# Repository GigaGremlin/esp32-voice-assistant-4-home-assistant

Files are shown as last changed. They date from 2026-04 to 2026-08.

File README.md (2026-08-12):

# 🎙️ ESP32 Voice-Assistant für Home Assistant

<div align="center">
  VA-Moon
</div>

---

## Über dieses Projekt

**(ESP32-S3 WROOM-1-N16-R8) Home Assistant Voice Assistant Pro Version**

Meinen Ersatz für den M5AtomEcho gibt es jetzt auch in der Pro Version als Voice Assistant für Home Assistant.

Die Pro Version meines “Voice Assistant“ unterscheidet sich von der Standardausführung durch ein zusätzlich integriertes Radarmodul, einen kleinen physikalischen Button auf der Rückseite und einen vorgeschalteten “CH224K USB-C Schnellladeregler“. Die nötige Pinbelegung für den Anschluss am “ESP32“ findet sich wie immer als Tabelle in meiner “YAML-Firmware-Datei“.

**Update: ab sofort funktioniert Music Assistant mit meiner letzten Firmware einwandfrei!!!**

Die Liste der Komponenten ist wie gewohnt sehr einfach und preiswert gehalten.

Ich verwende die üblichen Verdächtigen: einen Max98357A als Verstärker und ein INMP441 als Mikrofon. Die LED ist eine adressierbare WS2812 mit 5 Volt. Für die gestiegenen Anforderungen habe ich jetzt einen CH224K USB-C Schnellladeregler als Spannungsverteiler vorgeschaltet. Durch dessen Verwendung könnte man jetzt sogar mehrere LEDs anbinden (Einfach die LED-Anzahl in der YAML erhöhen) oder andere Sensor-Module einbinden.

Und was Preis und Leistung angeht, ist dieser Voice Assistant für Home Assistant, gemessen an vergleichbaren Assistenten, immer noch deutlich preiswerter und durch den integrierten Präsenzmelder ist er sogar überlegen, da Anbindung & Steuerung nicht über eine zusätzliche Bluetooth- oder ZigBee-Verbindung erfolgt.

* **Baukosten ohne den 3D Druck:** ca. 35€
* **Geschätzter Marktwert:** 80-120 Euro

---

**(ESP32-S3 WROOM-1-N16-R8) Home Assistant Voice Assistant Pro Version**

My replacement for the M5AtomEcho is now also available in a Pro Version as a Voice Assistant for Home Assistant.

The Pro Version of my "Voice Assistant" differs from the standard model by including an additional radar module, a small physical button on the back, and a preceding "CH224K USB-C Fast Charge Controller". As always, the necessary pinout for connecting to the "ESP32" can be found as a table in my "YAML firmware file."

**Update: Music Assistant is now working perfectly with my latest firmware!!!**

The component list is, as usual, kept very simple and inexpensive. I am using the usual suspects: a Max98357A as an amplifier and an INMP441 as a microphone. The LED is an addressable WS2812 operating at 5 volts. To meet the increased demands, I have now installed a CH224K USB-C Fast Charge Controller as a preceding voltage distributor. By using it, you could now even connect multiple LEDs (simply increase the LED count in the YAML) or integrate other sensor modules.

Regarding price and performance, this Voice Assistant for Home Assistant is still significantly less expensive compared to similar assistants, and due to the integrated presence detector, it is even superior, as connection and control do not require an additional Bluetooth or ZigBee link.

* **Construction costs without 3D print:** approx. €35
* **Estimated market value:** €80–120

---

> [!NOTE]
> **Anschlussbelegung:** Die notwendige Anschlussbelegung ist natürlich in die YAML-Datei integriert. / The necessary pin assignment is integrated into the YAML file.

<div align="center">
  Pinbelegung
</div></div>

---
<div align="center">
OldPinOut
</div></div>

---

<div align="center">
  InsideView
</div></div>

---
* **Achtung !!!** - Da ich für meine letzten S3 Module die preiswerten Versionen von Ali gekauft habe und es mir nicht gelungen ist darauf die gleiche Standardkonfiguration zum laufen zu bringen, wie bei meinen Marken Modulen,
verstehe ich jetzt auch die Probleme, die einige von Euch beim Nachbau hatten.
* Um diese Probleme direkt zu beseitigen, habe ich nun doch die GPIO's für den MAX98357 und das INMP441 getrennt und eine eigene Firmware, basierend auf der neuen Verkabelung erstellt.
* Mit dieser Änderung funktionieren dann auch die Klon-Module als Voice Assistant und Music Assistant Satelliten. 
* Und das lästige Störgeräusch beim Booten ist damit ebenfalls Geschichte.
* **Das Video zur Neuerung ist noch in Arbeit**
---
<div align="center">
NewPinOut
</div></div>

---

# YouTube: ESP32 S3 Voice Assistant Pro

<div align="center">
  <a href="https://youtu.be/G6M7URdppqs">
    Video Anleitung
  </a>
  <p>📺 <i>Klicke auf das Bild, um das Video auf YouTube zu starten</i></p>
</div>

---

## 🛠️ Downloads & Firmware

Wähle die passende Version für deine Hardware:

### 1. Firmware old PinOut Version (YAML Dateien)
* 📥 [**Standard Version**](firmware/standard/) – Ohne Radar-Modul.
* 📥 [**Radar Version**](firmware/radar/) – Optimiert für Anwesenheitserkennung.
* *******************************************************************************
### 2. Firmware new PinOut Version (YAML Dateien)
**(Achtung - Bitte nur noch die Neue Version verwenden !!!)**
* 📥 [**New PinOut Version - Universal Version**](firmware/new/) – Optimiert für alle S3 Module.
  
**Aber was, wenn ich kein Radar-Modul will ??!**

... kein Problem, dann diese Kabel einfach weglassen...
Meine neue Firmware-GUI Version kann jetzt beide Varianten aus der 
neuen Universal-Firmware für Deine Home Assistant Ansprüche erstellen. 

Wer kein LD2410 Radar Modul nutzt, kann einfach den Haken in der GUI weglassen. 
Die Standardeinstellung ist ausgeschaltet, aber alle anderen sollten den Haken setzen! 
Hier kann jetzt auch direkt an einigen anderen “Stellschrauben“ gedreht werden.

* *******************************************************************************
* 📁 [Alle Firmware-Versionen durchsuchen](firmware/)
* *******************************************************************************

### 3. Tools & Personalisierung
**Achtung !!!** - für die NEUE universal Firmware gibt 

es auch ein neues GuiTool, **New-ESPhome_GUI.exe**

* 🖥️ [**GGFW Personalizer Tool (EXE)**](gui-tool/)
* 🖥️ [**New-ESPhome_GUI (EXE)**](gui-tool/)
  
**Nutze dieses Tool, um WLAN-Daten und Namen direkt in der Firmware anzupassen.**
* *******************************************************************************

### 4. Gehäuse & 3D-Druck
* 📐 [3D-Druck Dateien (STL)](3D-Print/)

**Es gibt jetzt auch eine neue universal 2,5"-Speaker-Halterung die mit M4 Schrauben funktioniert.**
* *******************************************************************************

### 5. Home Assistant - Integration
* 🏠 [**Home Assistant Beispiel-Konfigurationen**](home-assistant-examples/)

**Hier findest du YAML-Ausschnitte für Dashboards und Automatisierungen.**

</div></div>

---

<div align="center">
<i>Zuletzt aktualisiert: August 2026</i>
</div>

</div></div>   
<div align="center">
   <a href="https://gigagremlin.de">
    
  </a>
</div>

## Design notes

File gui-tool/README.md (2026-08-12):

# GigGremlin Firmware Personalizer GUI

**Dieses kleine GUI soll dabei helfen die Firmware einfacher an die persönlichen Bedürfnisse im Netzwerk anzupassen.**
**So kann der Name und die IP schnell geändert werden. Das ist gerade bei mehreren Geräten hilfreich und spart Zeit.**
**Darüber hinaus kann ich nur jedem dazu raten eine feste IP für seine VA’s zu verwenden.**

This small GUI is designed to help you easily adapt the firmware to your individual network needs. 
For example, you can quickly change the name and IP address. This is especially helpful with multiple devices 
and saves time. Furthermore, I strongly recommend using a static IP address for your virtual assistants.

--- 
GigGremlinFirmwarePersonalizerGUI

---
GigGremlinFirmwarePersonalizerGUI-2

---
# **Achtung** - neues Firmware GUI für das **NEUE** Pin Layout !!!

---
GG-VA-FWTool

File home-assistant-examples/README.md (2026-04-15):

# 🏠 Home Assistant Integration
So sieht meine Einbindung in HomeAssistant aus 
Ich habe in meinem “Home Assistant“ eine Extraseite für meine Pro VA's erstellt und bequem zwei Geräte nebeneinander 
darstellen / überwachen, ohne das es zu eng auf dem Bildschirm wird. Bei dieser Darstellung kann man die Raumbelegung 
überwachen, ohne dabei auf eine Kamera zurückgreifen zu müssen, was sich besonders für Umkleidekabinen oder ein 
Schlafzimmer eignet und sich auch über eine Mobile Verbindung gut nutzen lässt. 

## 📊 Dashboard Vorschau

**Normalmodus / Standard**

Radar-S3ProCombi-1-HA

**Engineering Modus eingeschaltet**
Radar-S3ProCombi-2-HA

### Installation
1. Kopiere den Code aus der Datei `ESPHome-S3-Box_Ver4-Radar-HA-Vorlage.yaml`.
2. Erstelle eine neue Karte in HA und füge den Code ein.
3. Passe die Entitäten-Namen an dein Gerät an.
#
 **Wichtig - Vor der Nutzung müssen alle Vorkommen von**
 *esp32s3_va00*
 **durch den eigenen Modul-Namen ersetzt werden !!!**

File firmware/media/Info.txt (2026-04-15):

Um das lästige “Kratzen” oder auch den “DigiFart“ des Lautsprechers beim Booten zu vermeiden verwende ich zwei WAV-Dateien bei der Initialisierung und vermeide damit die Störgeräusche so gut es geht. Die letzten HA-Updates machen es aber nicht leicht hierfür das richtige Timing zu bestimmen.

To avoid the annoying "scratching" or "DigiFart" sound from the speaker during boot, I use two WAV files during initialization, thus minimizing the interference as much as possible. However, recent HA updates have made it difficult to determine the correct timing for this.

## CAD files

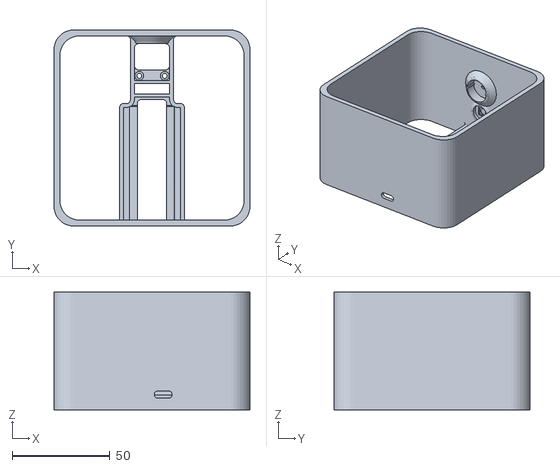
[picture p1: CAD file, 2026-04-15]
3D-Print/NoRadar/ESPHome-S3-Box_Ver1-CenterBox.stl
100.0 x 100.0 x 60.0

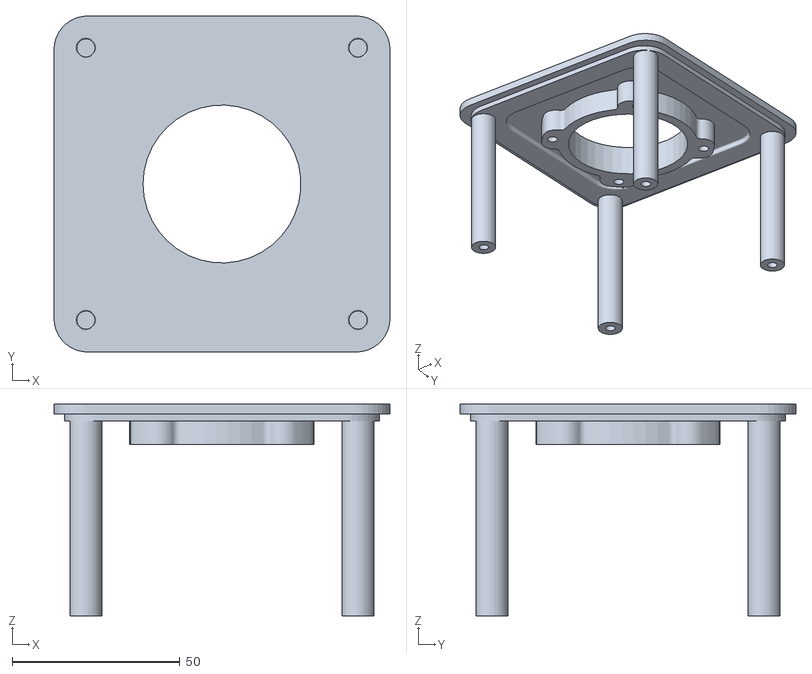
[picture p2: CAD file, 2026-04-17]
3D-Print/Radar/ESPHome-S3-Box-Universal-M4-2.5SpeakerMount.stl
100.0 x 100.0 x 63.0

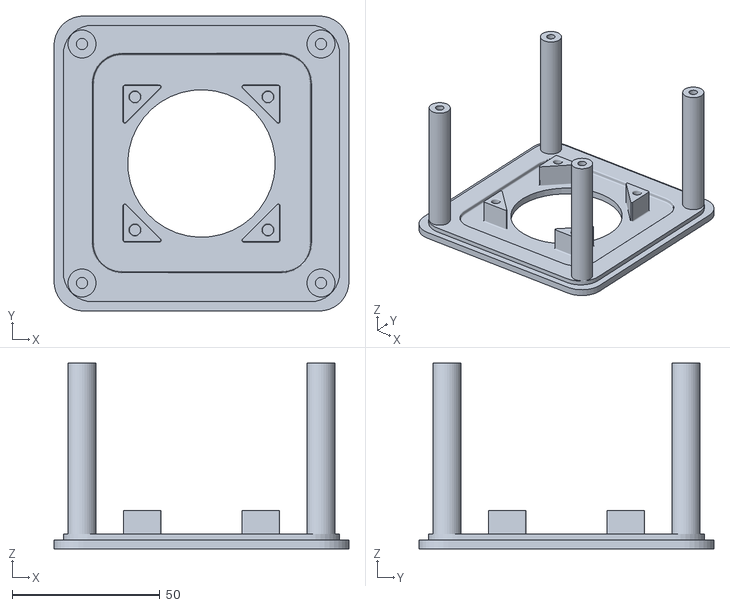
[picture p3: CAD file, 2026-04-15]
3D-Print/NoRadar/ESPHome-S3-Box_Ver1-Speaker.stl
100.0 x 100.0 x 63.0

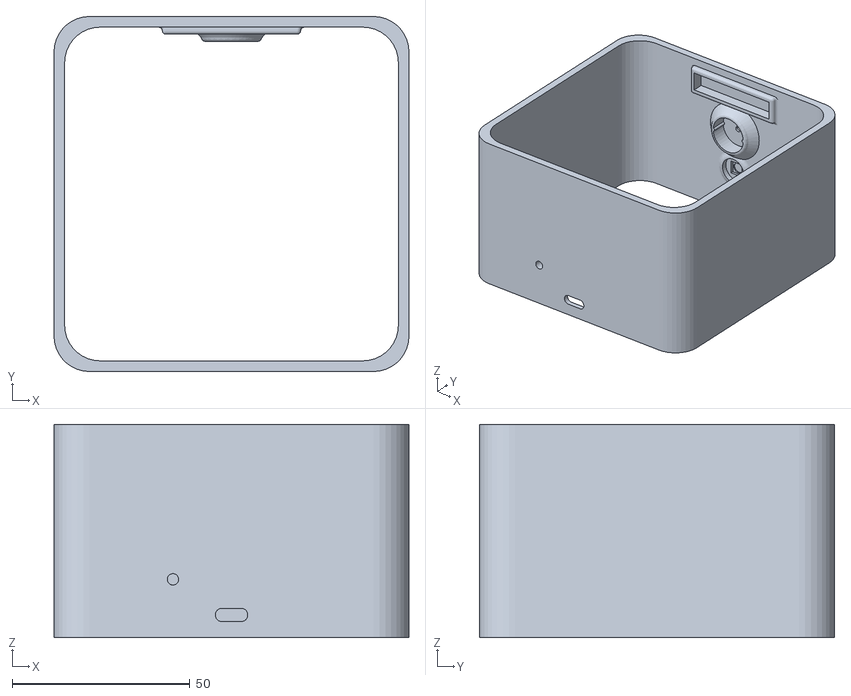
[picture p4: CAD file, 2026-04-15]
3D-Print/Radar/ESPHome-S3-Box_Ver4-Radar-Center-HLK-LD2410B.stl
100.0 x 100.0 x 60.0

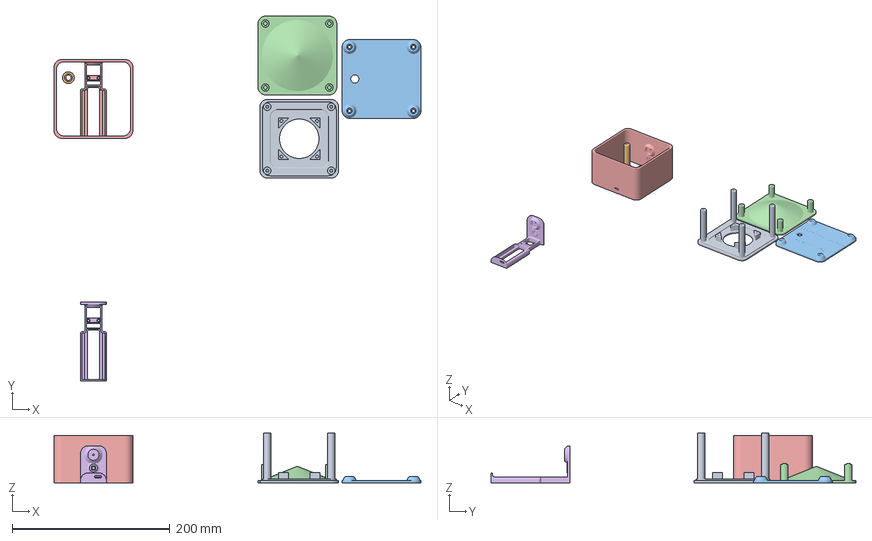
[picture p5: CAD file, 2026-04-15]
3D-Print/NoRadar/ESPHome-S3-Box_Ver_1.3mf
464.8 x 462.1 x 63.0 mm
ESPHome-S3-Box_Ver2-6-SpeakerStand.stl
ESPHome-S3-Box_Ver2-6-Lid2.stl
BottomBox_5.stl
Zusammenbau
ESPHome-S3-Box_Ver2-6-CenterBox-2.stl
ESPHome-S3-CableMountingFrame.stl

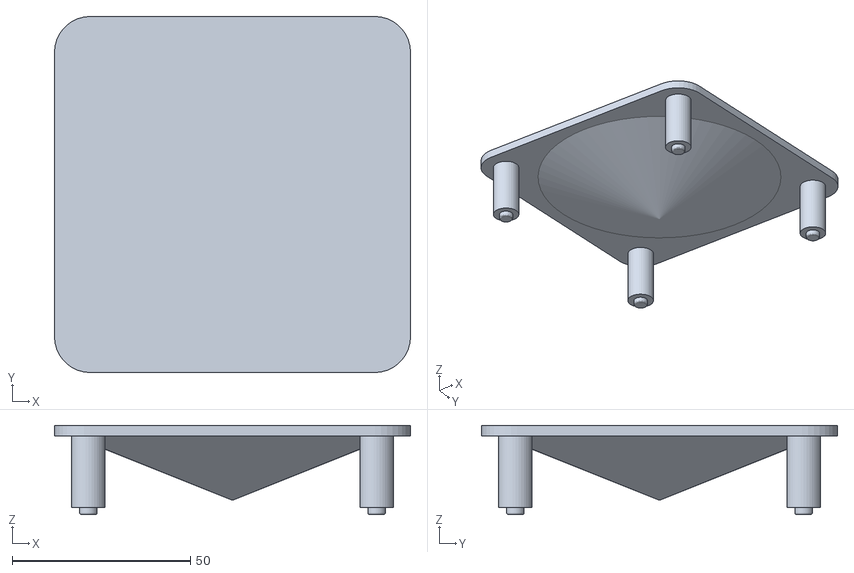
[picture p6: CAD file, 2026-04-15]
3D-Print/Radar/ESPHome-S3-Box_Ver4-Radar-Top-NoLogo.stl
100.0 x 100.0 x 25.0

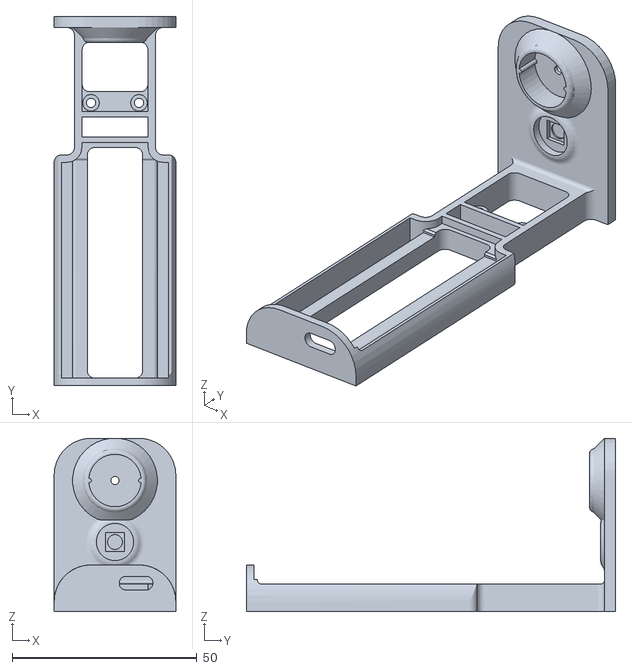
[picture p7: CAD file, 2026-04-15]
3D-Print/NoRadar/ESPHome-S3-Box_Ver1-TestRig.stl
33.0 x 100.0 x 47.0

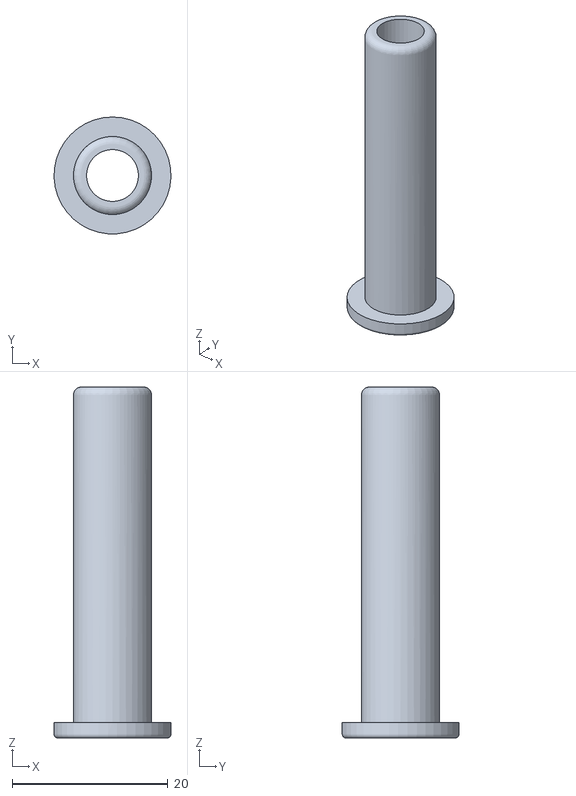
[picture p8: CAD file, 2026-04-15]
3D-Print/Radar/ESPHome-S3-Box_Ver4-Radar-ReflexTube.stl
15.0 x 15.0 x 45.0

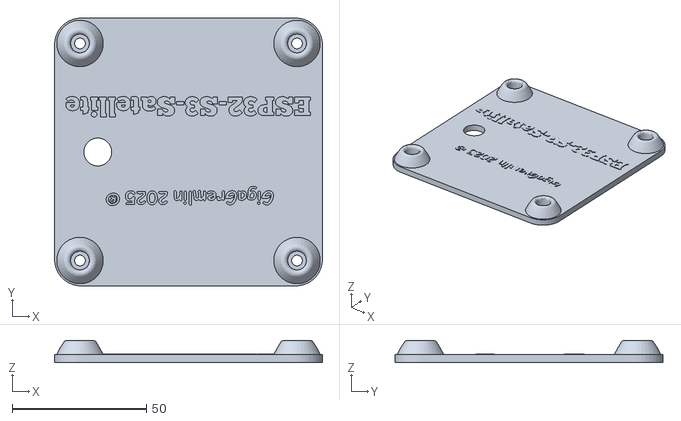
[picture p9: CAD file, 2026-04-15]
3D-Print/NoRadar/ESPHome-S3-Box_Ver1-Bottom.stl
100.0 x 100.0 x 8.21

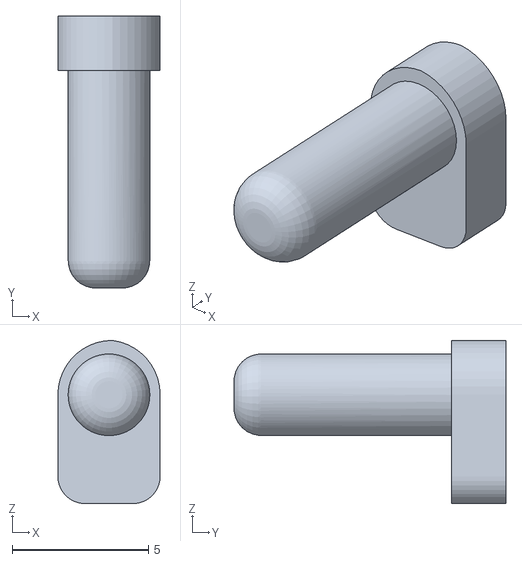
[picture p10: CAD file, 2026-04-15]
3D-Print/Radar/ESPHome-S3-Box_Ver4-Radar-SwitchPin.stl
3.76 x 10.00 x 6.00

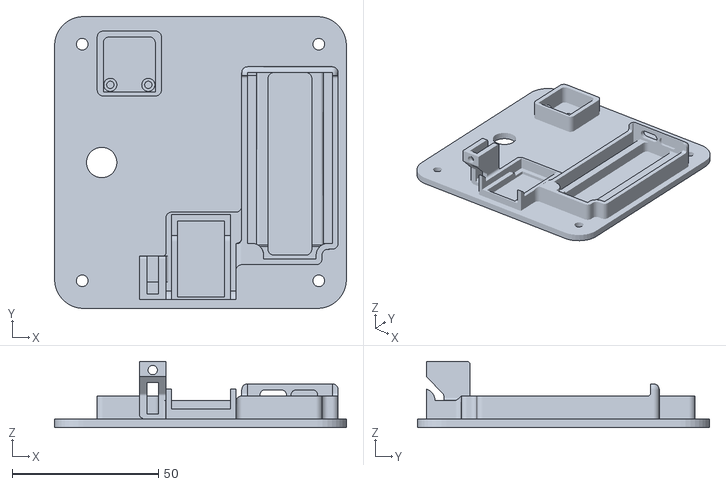
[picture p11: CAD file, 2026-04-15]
3D-Print/Radar/ESPHome-S3-Box_Ver4-Radar-BottomPlate.stl
100.0 x 100.0 x 22.7

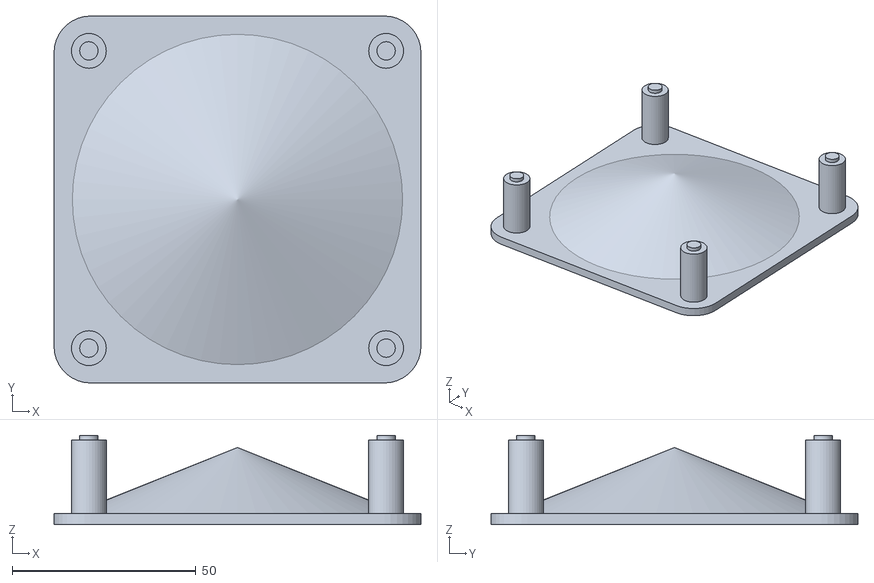
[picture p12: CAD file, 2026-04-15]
3D-Print/NoRadar/ESPHome-S3-Box_Ver1-TopCone.stl
100.0 x 100.0 x 24.3

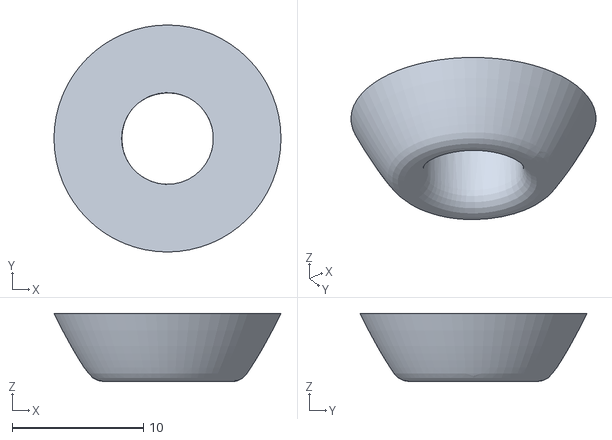
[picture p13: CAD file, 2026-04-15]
3D-Print/Radar/ESPHome-S3-Box_Ver4-Radar-Feet.stl
17.3 x 17.3 x 5.21

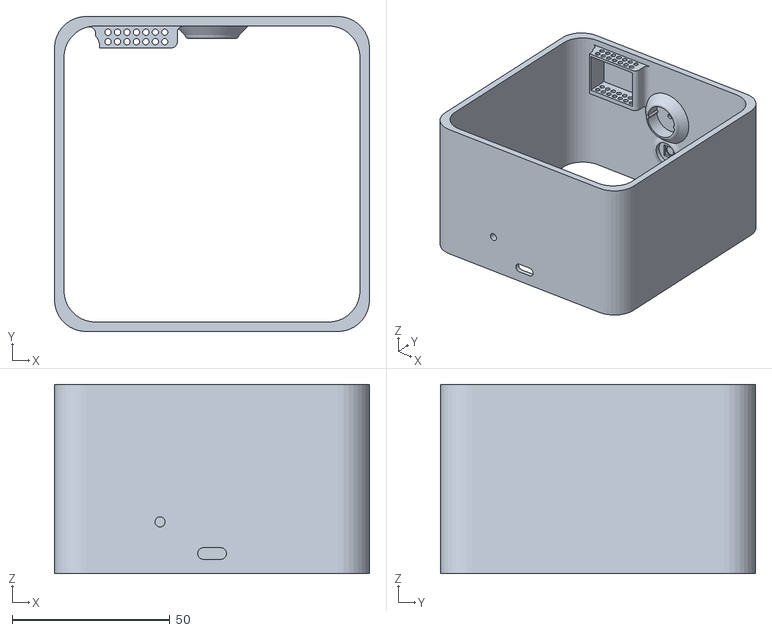
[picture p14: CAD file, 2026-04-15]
3D-Print/Radar/ESPHome-S3-Box_Ver4-Radar-Center-HLK-LD2410C.stl
100.0 x 100.0 x 60.0

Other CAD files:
3D-Print/NoRadar/ESPHome-S3-Box_Ver1-ReflexTube.stl
3D-Print/Radar/ESPHome-S3-Box_Ver4-Radar-AiyimaSpeakerMount.stl

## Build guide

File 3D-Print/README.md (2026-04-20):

# 🎙️ Update: April 2026

---

### 🛠️ Hardware Enhancement
**DE:** Die 3D-Gehäuse-Dateien wurden um den versprochenen **Halter für einen Standard 2,5-Zoll-Lautsprecher** erweitert.  
**EN:** *I have now also added the promised holder for a standard 2.5-inch speaker to the 3D case files.*

---

### 💾 Firmware & Software
Die aktuellste Firmware zum Voice Assistant Projekt findest du immer hier:  
*The latest firmware for the Voice Assistant project can always be found at this link:*



---

### 📸 Impressionen / Gallery

<div align="center">
  NewSpeakerMount-3
  NewSpeakerMount-1
  NewSpeakerMount-2
</div>

<p align="center">
  <em>Visualisierung der neuen Lautsprecher-Halterung / Visualization of the new speaker mount.</em>
</p>

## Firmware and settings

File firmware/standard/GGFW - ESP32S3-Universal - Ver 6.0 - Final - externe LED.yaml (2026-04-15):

# GGFW - ESP32S3-VAxx - Ver 6.0 - Final - external LED + MusicAssistant
# ESP32-S3 DevKitC-1 Pinout für Voice Assistant mit externer LED
################################################################
# GPIO5 -> MAX98357A (BCLK) & INMP441 (SCK)
# GPIO6 -> MAX98357A (LRC)  & INMP441 (WS)
# GPIO7 -> INMP441 (SD)
# GPIO8 -> MAX98357A (DIN)
# GPIO18 -> external LED
# INMP441 VCD -> 3,3Volt
# INMP441 GND -> GND
# INMP441 L/R -> GND
# MAX98357A Vin -> 5Volt
# MAX98357A GND -> GND
# MAX98357A SD -> left open (or GND)
# MAX98357A Gain -> 300 Ohm to GND for 12dB (open 9 dB)
################################################################

substitutions:
  name: esp32s3-va00            # Beispiel - Name !!!
  friendly_name: ESP32S3-VA00   # Beispiel - Friendly Name !!!

esphome:
  name: ${name}
  name_add_mac_suffix: false
  friendly_name: ${friendly_name}
  min_version: 2025.5.0
  on_boot:
    priority: 600.0 # Stellt sicher, dass dies früh ausgeführt wird
    then:
      - output.turn_off: onboard_led_off_output # Schaltet den Output an GPIO48 aus
      # Sound 1 nach der Initialisierung
      - delay: 4s # Gibt dem System Zeit zum Starten bevor es die Datei abspielt
      - media_player.speaker.play_on_device_media_file:
          id: echo_media_player
          media_file: init_sound_file # Verwendet die neue, stumme Initialisierung
          announcement: true            
      # Sound 2 nach erfolgreichem Bootvorgang
      - delay: 18s # Gibt dem System Zeit zum Starten bevor es die Datei abspielt
      - media_player.speaker.play_on_device_media_file:
          id: echo_media_player
          media_file: boot_sound_wave_file # Verwendet die neue, leisere Startdatei
          announcement: true          
          

esp32:
  board: esp32-s3-devkitc-1
  cpu_frequency: 240MHz
  framework:
    type: esp-idf
    sdkconfig_options:
      CONFIG_IDF_TARGET_ESP32S3: y
      CONFIG_ESP_SYSTEM_MEMPROT_FEATURE: y
      CONFIG_HEAP_TLSF_USE_EXTERNAL_MEM: y
      CONFIG_HEAP_IRAM_SIZE: "0x80000"
      CONFIG_HEAP_DRAM_SIZE: "0x200000"
      CONFIG_ESP_DEFAULT_CPU_FREQ_MHZ_240: y

psram:
  mode: octal
  speed: 80MHz   ### Speed von 40 -> 80 (S3)

logger:

api:
  encryption:
    key: !secret esphome_api_encryption_key

ota:
  - platform: esphome
    id: ota_esphome
  - platform: web_server  # Add this for web-based OTA uploads

wifi:
  #use_address: 192.168.1.2    # IP ist Optional, nicht entfernen, wenn DHCP bevorzugt wird !
  ssid: !secret wifi_ssid
  password: !secret wifi_password

web_server:
  port: 80    # Stellt über die IP eine eigene Website zur Verfügung

# captive_portal:

improv_serial:

button:
  - platform: factory_reset
    id: factory_reset_btn
    name: Factory reset

# --- START DES AUDIO-BLOCKS (Ersetzt I2S, Mikrofon, Speaker und Media_Player) ---
i2s_audio:
  - id: i2s_audio_bus
    i2s_lrclk_pin: GPIO6  # LRC Pin für MAX98357A & INMP441
    i2s_bclk_pin: GPIO5   # BCLK/SCK Pin für beide I2S Geräte

microphone:
  - platform: i2s_audio
    id: echo_microphone
    i2s_audio_id: i2s_audio_bus
    i2s_din_pin: GPIO7    # SD Pin vom INMP441
    adc_type: external
    pdm: false
    sample_rate: 16000    # Standard für Spracherkennung
    channel: left

speaker:
  - platform: i2s_audio
    id: audio_output_speaker
    i2s_audio_id: i2s_audio_bus
    i2s_dout_pin: GPIO8    # DIN Pin vom MAX98357A
    dac_type: external
    bits_per_sample: 16bit
    sample_rate: 44100     # NEU: 44.1kHz für Musik-Streaming via Music Assistant
    channel: mono
    buffer_duration: 1000ms # NEU: Größerer Puffer für stabileres Audio-Streaming
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

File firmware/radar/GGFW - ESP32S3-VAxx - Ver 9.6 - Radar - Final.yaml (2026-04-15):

# GGFW - ESP32S3-VA5 Ver 9.6
# ESP32-S3 DevKitC-1 Pinout für Voice Assistant-Pro
################################################################
# GPIO5 -> MAX98357A (BCLK) & INMP441 (SCK) -> rot
# GPIO6 -> MAX98357A (LRC)  & INMP441 (WS) -> Weiss
# GPIO7 -> INMP441 (SD) -> grün
# GPIO8 -> MAX98357A (DIN) -> grün
################################################################
# GPIO43 -> RX des LD2410 -> rot
# GPIO44 -> TX des LD2410 -> grün
# GPIO42 -> OUT-Pin des LD2410 -> Weiss
#--------------------------------------
#   5Volt des LD2410 -> rot
#   GND  des LD2410  -> schwarz
################################################################
# GPIO18 -> ext. LED ->  grün
#   ext. LED 5Volt -> rot
#   ext. LED GND -> Weiss
################################################################
# GPIO20 -> Button -> rot
#   GND -> Button -> schwarz
################################################################
#   MAX98357A Vin -> 5Volt -> rot
#   MAX98357A GND -> GND -> schwarz
#   MAX98357A SD -> left open (or GND) <-
#   MAX98357A Gain -> 300Ohm to GND for 12dB (open 9 dB) <-
#--------------------------------------
#   INMP441 VCD -> 3,3Volt -> rot
#   INMP441 GND -> GND -> schwarz
#   INMP441 L/R -> GND -> GND
################################################################

substitutions:
  name: esp32s3-va00            # Beispiel - Name !!!
  friendly_name: ESP32S3-VA00   # Beispiel - Friendly Name !!!

esphome:
  name: ${name}
  name_add_mac_suffix: false
  friendly_name: ${friendly_name}
  min_version: 2025.5.0
  on_boot:
    # priority: 600.0 # Stellt sicher, dass dies früh ausgeführt wird
    priority: -100.0  # <--- ÄNDERUNG: Ganz spät ausführen, wenn alles andere stabil steht!
    then:
      - output.turn_off: onboard_led_off_output # Schaltet den Output an GPIO48 aus
      # Sound nach erfolgreichem Bootvorgang
      # - delay: 4s  # Gibt dem System Zeit zum Starten bevor es die Datei abspielt
      - delay: 10s   # Mehr Zeit geben
      - media_player.speaker.play_on_device_media_file:
          id: echo_media_player
          media_file: init_sound_file # Verwendet die neue, stumme Initialisierung
          announcement: true
      # Sound 2 nach erfolgreichem Bootvorgang
      - delay: 18s # Gibt dem System Zeit zum Starten bevor es die Datei abspielt
      - media_player.speaker.play_on_device_media_file:
          id: echo_media_player
          media_file: boot_sound_wave_file # Verwendet die neue, leisere Startdatei
          announcement: true          

esp32:
  board: esp32-s3-devkitc-1
  cpu_frequency: 240MHz
  framework:
    type: esp-idf
    sdkconfig_options:
      CONFIG_IDF_TARGET_ESP32S3: y
      CONFIG_ESP_SYSTEM_MEMPROT_FEATURE: y
      CONFIG_HEAP_TLSF_USE_EXTERNAL_MEM: y
      CONFIG_HEAP_IRAM_SIZE: "0x80000"
      CONFIG_HEAP_DRAM_SIZE: "0x200000"
      CONFIG_ESP_DEFAULT_CPU_FREQ_MHZ_240: y

psram:
  mode: octal
  # speed: 80MHz   # Speed von 40 -> 80 (S3)
  speed: 40MHz     # Von 80 MHz auf 40 MHz reduziert für bessere Stabilität
  ignore_not_found: false   # If audio stutters, and your device has PSRAM, add (PSRAM configured with ignore_not_found: false) so that the networking stack uses higher performance optimization settings.
  
logger:
  # Standard-Logger-Konfiguration
  # level: VERY_VERBOSE # Dies hinzufügen oder auf VERY_VERBOSE setzen
#  logs: # Geändert von DEBUG auf INFO
#    component.microphone: INFO
#    component.i2s_audio: INFO
#    component.voice_assistant: INFO
#    component.ld2410: INFO

api:
  encryption:
    key: !secret esphome_api_encryption_key

ota:
  - platform: esphome
    id: ota_esphome
  - platform: web_server  # Add this for web-based OTA uploads

web_server:
  port: 80    # Stellt über die IP eine eigene Website zur Verfügung

wifi:
  # use_address: 192.168.1.2    # IP ist Optional, nicht entfernen, wenn DHCP bevorzugt wird !
  ssid: !secret wifi_ssid       # Wifi SSID
  password: !secret wifi_password     # Wifi Password
  # post_connect_roaming: false  # To disable
  power_save_mode: NONE # Verhindert, dass das WLAN-Modul kurz schlafen geht

# captive_portal:

improv_serial:

button:
  - platform: factory_reset
    id: factory_reset_btn
    name: Factory reset

i2s_audio:
  - id: i2s_audio_bus
    i2s_lrclk_pin: GPIO6  # LRC Pin für MAX98357A & INMP441
    i2s_bclk_pin: GPIO5   # BCLK/SCK Pin für beide I2S Geräte

microphone:
  - platform: i2s_audio
    id: echo_microphone
    i2s_audio_id: i2s_audio_bus
    i2s_din_pin: GPIO7    # SD Pin vom INMP441
    adc_type: external
    pdm: false
    sample_rate: 16000    # Standard für Spracherkennung
    channel: left     # Wichtig: Passt zur L/R-Pin-Verbindung auf GND
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

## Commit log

2026-04-15 GGFW - ESP32S3 - Universal - Ver 5.0 - Final - externe LED.yaml
    Es handelt sich hier um die ursprüngliche Version meines VA (Voice Assistent) OHNE Radar und die notwendigen Updates, die sich aus ESP-Home und Home Assistant Updates ergeben haben!!!
    This is the original version of my VA (Voice Assistant) WITHOUT radar and the necessary updates resulting from ESP-Home and Home Assistant updates!!!
2026-04-15 Update GGFW - ESP32S3 - Universal - Ver 5.0 - Final - externe LED.yaml
    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
2026-04-15 Create GGFW-ESP32S3-Universal-Ver-6.0-Final-externe-LED
    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
2026-04-15 Create GGFW - ESP32S3-VAxx - Ver 7.1nr.yaml
    Diese Version ist mit den aktuellen Änderungen und Updates am stabilsten.
    This version is the most stable with the latest changes and updates.
2026-04-15 Create GGHAVA-ESP32S3 - Universal Firmware Ver. 7.2 (Ger).yaml
    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
2026-04-15 3d-Print directory
    [ESPHome-S3-Box_Ver4-Radar-AiyimaSpeakerMount.stl, ESPHome-S3-Box_Ver4-Radar-BottomPlate.stl, ESPHome-S3-Box_Ver4-Radar-Center-HLK-LD2410B.stl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]
